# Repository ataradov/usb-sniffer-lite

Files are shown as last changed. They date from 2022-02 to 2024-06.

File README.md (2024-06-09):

# Usb Sniffer Lite for RP2040

This is a simple USB sniffer based on a Raspberry Pi RP2040. It supports Low Speed and
Full Speed modes.

The firmware presents itself as a virtual COM-port (VCP), so no additional software
is necessary and it is compatible with all operating systems.

Here are a couple of example capture logs for the [enumeration](doc/usb_fs_enumeration.txt)
and a regular [data transfer](doc/usb_fs_data.txt).

The compiled binary is available [here](bin/UsbSnifferLite.uf2). Boot RP2040 into
the BootROM mode and copy the UF2 file to the drive.

This sniffer has no packet decoding capabilities, but there is an excellent online
[USB Descriptor and Request Parser](https://eleccelerator.com/usbdescreqparser/)
that is very helpful with decoding of the standard descriptors and requests.

The compiled binary needs to have CRC value updated to be recognized by the RP2040.
This can be done using [bin2uf2](https://github.com/ataradov/tools/tree/master/bin2uf2) tool.

## Hardware Connections

USB D+ and D- signals can be directly connected to the MCU pins. The default
pin assignments are shown in the following table:

| RP2040 Pin | Function | USB Cable Color |
|:---:|:---:|:-----:|
| GND | Ground | Black |
| GPIO 10 | D+ | Green |
| GPIO 11 | D- | White |
| GPIO 12 | Start (internal) | N/A |
| GPIO 18 | Trigger | N/A |
| GPIO 25 | Status LED | N/A |
| GPIO 26 | Error LED | N/A |

The easiest way to connect the signals to the Raspberry Pi Pico board is to splice
the USB cable. It does not have to be pretty. Below is a picture of a cable that
took less than 10 minutes to make. Feel free to make it prettier.

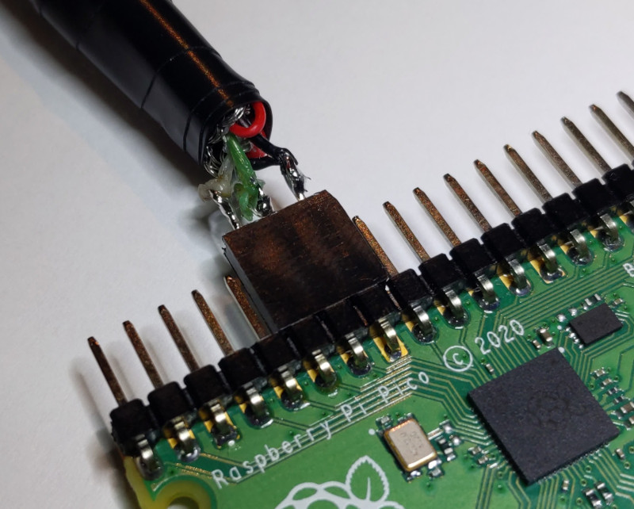
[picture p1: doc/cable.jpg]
USB Cable


[Here](doc/Hardware.md) are some pictures of a cleaner version based on
the [custom breakout board](https://github.com/ataradov/breakout-boards/tree/master/rp2040).

Trigger input is internally pulled up and the active level is low. When trigger is
enabled in the settings, the capture would pause until the trigger pin is pulled low.
Given the limited size of the capture buffer, trigger mechanism provides a way for
the debugged target to mark the part of interest.

## Dedicated Hardware

There is now a dedicated board. It integrates FE8.1 USB HUB, so you only need one
connection to the host PC. This simplifies setup a lot and eliminates wiring mess
that usually happens when working with USB sniffers.

Normally it is not advised to use the same host port for the sniffer and the target device,
but since in this case only USB Low Speed and Full Speed modes are supported, there
is plenty of bandwidth for both devices.

Schematics and Gerber files are available in the [hardware](hardware/) directory.

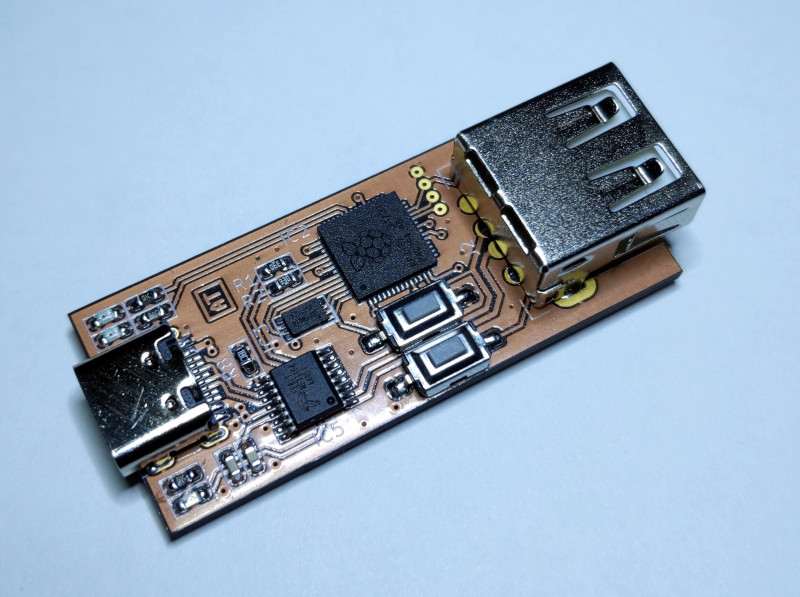
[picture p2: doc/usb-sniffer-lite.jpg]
USB Sniffer Lite PCB


## Settings

The following settings are supported:

* Capture speed (e) -- Low / Full
* Capture trigger (g) -- Enabled / Disabled
* Capture limit (l) -- 100/200/500/1000/2000/5000/10000 packets / Unlimited
* Time display format (t) -- Relative to the first packet / previous packet / SOF / bus reset
* Data display format (a) -- Full / Limit to 16 bytes / Limit to 64 bytes / Do not display data
* Fold empty frames (f) -- Enabled / Disabled

A frame is delimited by the SOF packet in the Full Speed mode or by a keep-alive signal in
the Low Speed mode.

An empty frame is a frame that contains no packets other than IN/NAK and contains no packets
with errors detected. Folding of the empty frames shortens the displayed information by
combining consecutive empty frames into one entry, since they don't carry useful information,
but happen very often in a typical USB transaction.

## Commands

The following commands are supported:

* Print the help message (h)
* Display current buffer (b)
* Start capture (s)
* Stop capture (p)

Once capture is started and the trigger condition is met, the sniffer captures the specified
number of packets. After the capture is done, the buffer is displayed using current settings.

The display settings may be adjusted without a new capture. Once the buffer is captured,
it is stored in the memory and can be displayed again using a `b` command.

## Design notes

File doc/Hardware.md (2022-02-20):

# Custom hardware version

This is the hardware based on the [custom breakout board](https://github.com/ataradov/breakout-boards/tree/master/rp2040):

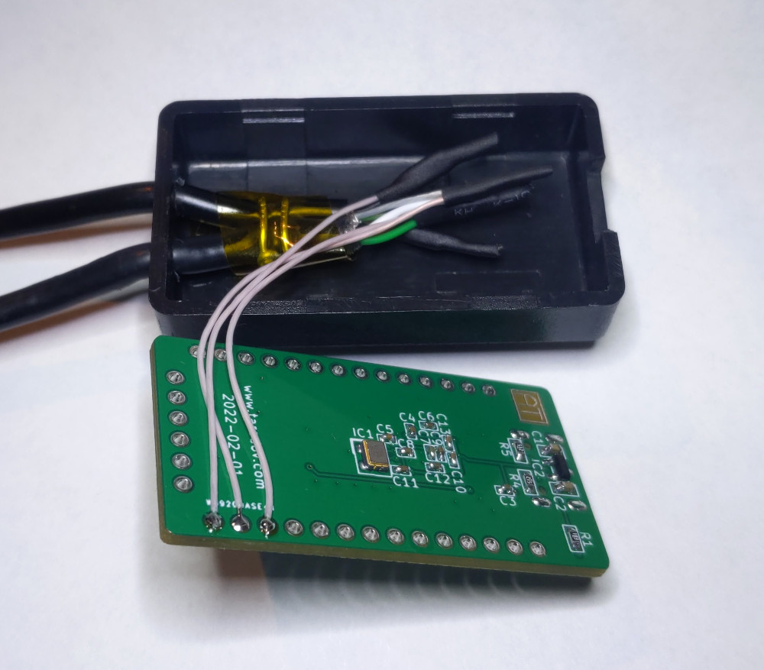
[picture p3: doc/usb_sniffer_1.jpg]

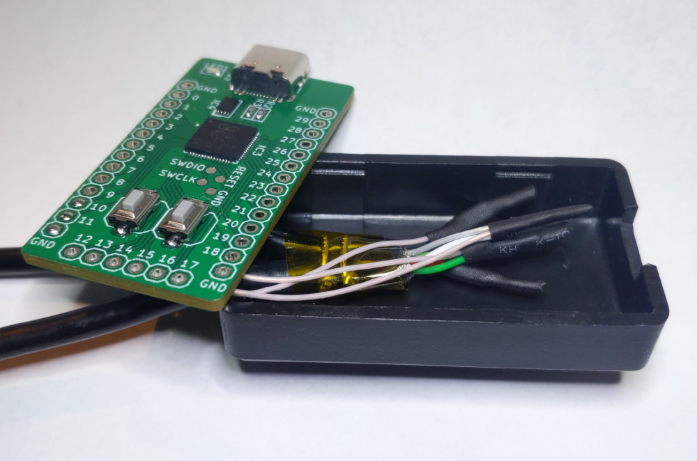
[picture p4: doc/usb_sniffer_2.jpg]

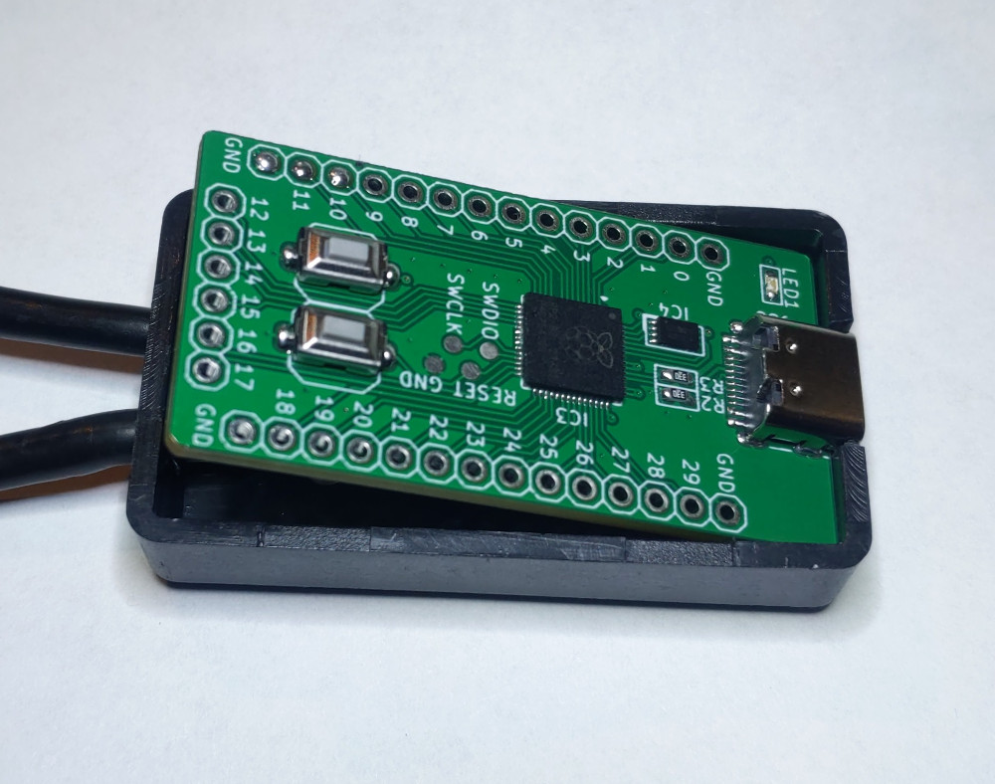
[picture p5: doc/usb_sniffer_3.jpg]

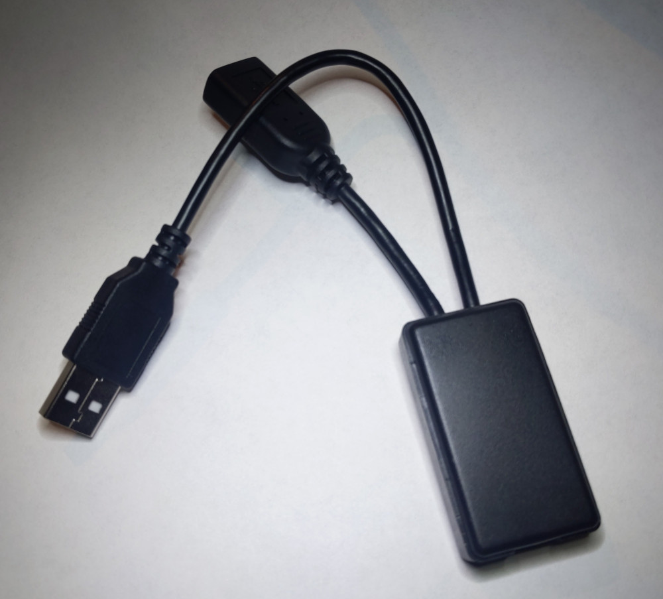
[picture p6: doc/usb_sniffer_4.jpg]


This uses a standard project box you can find on eBay or Aliexpress.
The suppliers change a lot, but usually you can find it by its dimensions: 1.97 x 1.1 x 0.59 inch / 50 x 28 x 15 mm.

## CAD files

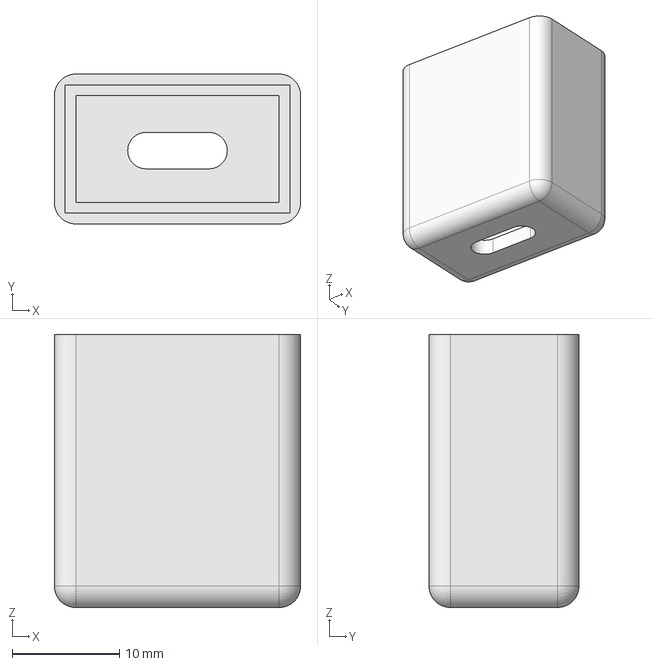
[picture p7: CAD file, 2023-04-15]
hardware/case/Case-Device.FCStd
23.0 x 14.0 x 25.5 mm

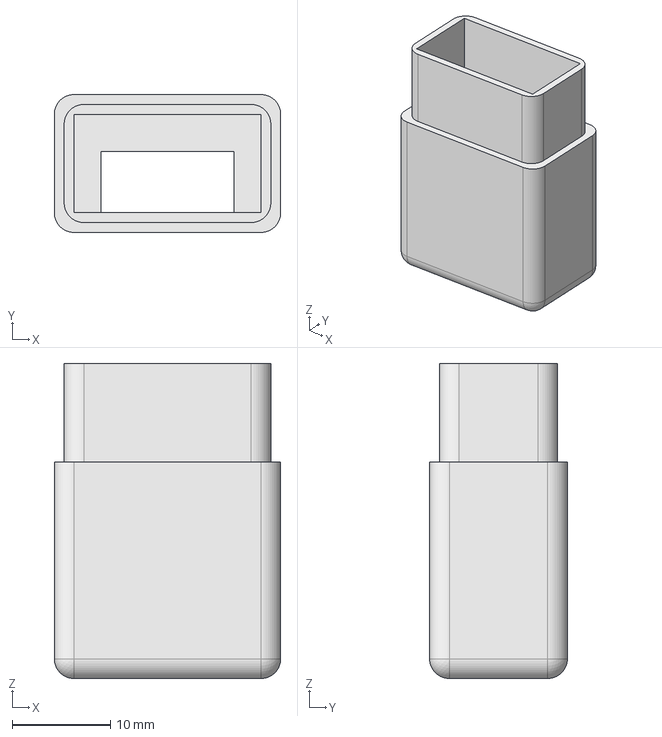
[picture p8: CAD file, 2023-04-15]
hardware/case/Case-Target.FCStd
23.0 x 14.0 x 32.0 mm

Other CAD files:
hardware/case/Case-Device.stl
hardware/case/Case-Target.stl

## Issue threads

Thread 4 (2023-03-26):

When I connect both the D+ and D- wires to the board, the connection between the testing Cool Disk with the computer is lost!

Pe3a-XaH, 2023-03-26:
Hello
Thanks for your interesting design.

I made the circuit and I saw its menu with the Putty terminal program and the LED was blinking and I used a cool disk for testing, but there was a problem.

When I disconnect one of the wires connected to GPIO 10 or GPIO 11 from the pico board, Cool Disk works and is recognized by the computer.

But when I connect both the D+ (Green) and D- (White) wires to the board, the connection between the Cool Disk and the computer is disconnected.

Please advise.

Thanks

ataradov, 2023-03-26:
What is Cool Disk?

Pe3a-XaH, 2023-03-26:
Hi,

I meant USB Flash Drives Storage.

In my country it is more famous as Cool Disk.

ataradov, 2023-03-26:
This sniffer will not be useful with flash drives. They still should function, but that depends on the quality of the connections. But sniffing will not work, since USB drives enumerate as High-Speed devices and this sniffer can only work with Full-Speed devices.

Try with something simpler, like a keyboard or a mouse.

Pe3a-XaH, 2023-03-26:
I tested with a non-smartphone and it seems to work.

I am using putty terminal with speed 576000 to communicate with pico.

But my question is how to save buffer data inside a file?
Because it is not completely possible using copy and paste.

I also get the following error at first, but after pressing the S key a couple of times to capture, it seems to get only small parts of the exchanged data correctly.

Capture started
Capture stopped
Synchronization error. Check your speed setting.

Capture buffer is empty

[When press (s) key many times ...]

1583027 : NAK
1583033 : IN: 0x02/2
1583036 : NAK
          :
          :
1583116 : NAK
1583122 : IN: 0x02/2
1583125 : NAK
1583133 : IN: 0x02/2
1583135 : DATA0 (7): 43 4d 47 52 3d 33 0d
1583143 : ACK
1583400 : IN: 0x02/2
1583403 : NAK
1583410 : IN: 0x02/2
1583413 : NAK
1583420 : IN: 0x02/2
          :
          :
1583946 : IN: 0x02/2
1583948 : NAK
   ... : Folded 1 frame

Capture buffer:
     0 : RESERVED
1869129088 : RESERVED
4154500480 : RESERVED
     0 : SPLIT: HubAddr=0x77, SC=1, Port=05, S=0, E=0, ET=2
   ... : Folded 1 frame
103123066 : SOF #551
103123078 : IN: 0x00/0
103123088 : IN: 0x00/0
103123098 : IN: 0x00/0
          :
          :
103123714 : IN: 0x00/0
103123724 : IN: 0x00/0
103123733 : IN: 0x00/0
103123829 : MDATA (280): 41 2a f8 07 f8 07 00 00 fc 03 01 00 fe 01 00 ff ...
    17 : DATA1 (4294967294):
    33 : DATA1 (43400): 25 06 20 15 27 2a 02 00 00 00 11 00 00 00 e9 8b ...
103141441 : IN: 0x00/0
103141450 : IN: 0x00/0
103141461 : IN: 0x00/0
          :
          :
103141568 : IN: 0x00/0
103141578 : IN: 0x00/0
     0 : RESERVED

[Or some time ... ]

  1021 : MDATA (280): 41 2a f8 07 f8 07 00 00 fc 03 01 00 fe 01 00 ff ff 7f 7f  ...

ataradov, 2023-03-26:
Get a better terminal that lets you save things into a file. The baudrate setting does not matter, since it is a purely virtual port.

The synchronization errors are common if device is already working and you start the capture. This sniffer assumes that the line is idle and if you start the capture in the middle of the packet, then it will not be able to synchronize properly. There may be a way to improve it, but I don't have time at the moment and in the end there is only so much PIO can do.

The optimal use for this is to start the capture, then plug int the device. This way you are guaranteed to start in the idle bus state.

Pe3a-XaH, 2023-03-26:
Thanks a lot

ataradov, 2023-04-12:
I've just pushed an update that should address a lot of synchronization issues. I expect it to be much more robust now.

Pe3a-XaH, 2023-04-24:
Hi,
Thank you for update.

I used the sniffer by Tana (https://github.com/tana/pico_usb_sniffer) for my job, because it makes Wireshark (.pcap) output.

Both of sniffers can not sniff high speed devices.

I used it series with a USB Isolator to reduce full speed devices to high speed mode, but it did  not work for me and makes many error packets.

Closed 2023-04-12.

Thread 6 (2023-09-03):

Synchronization issue

diggit, 2023-09-03:
Hi,
I have to say, this is really handy tool for USB FS debugging!
It already helped me to analyze some issues and improve bandwidth of device I am working on.
Now, I am trying to capture high load conditions. Unfortunately, I get:
```
Capture started
Capture stopped
Synchronization error. Check your speed setting.
```
I read though #4 and understood, that synchronization is problematic under load.
In my case, I have to open connection and then provide some data to load the bus. When I start capture and then open connection, packet buffer fills up before I manage to push some data.

Using trigger does not help, because it synchronizes on trigger.

Would it be possible to synchronize on start (s) and stay synced until capture is triggered?
Trigger input would serve only as a trigger for capture (storing into memory)

ataradov, 2023-09-03:
Does this happen every capture, or do you get some that work?

Do you use the most recent firmware? There was update in the most version where I wait for SE0 after the capture start. This would find the end of the packet if the capture was started in the middle.

Generally there is no way to analyze the data as it gets captured, there is not enough time for that. The only way to do this is to capture the buffer, then process it. This assumes the capture started at the beginning of the packet.

How do you use the trigger? The best way is to connect it to the device under test and in the firmware detect the condition when the traffic is about to start and set the trigger there. This way you will be starting before there is a lot of traffic. Manual triggering is essentially equivalent to the manual start without a trigger.

diggit, 2023-09-09:
I was not able to get a single sync with bus heavily loaded with Bulk IN data packets (CDC ACM, 6~18 bytes in size).
Used compiled binary linked in readme: https://github.com/ataradov/usb-sniffer-lite/blob/main/bin/UsbSnifferLite.uf2
Trigger was just a simple button. There is no simple way of triggering just before bus gets loaded.

ataradov, 2023-09-09:
Was it the most recent version of the file? It was updated multiple times and only the latest version contains sync improvements.

This behavior with the latest version is unexpected. I would debug it a bit. Capture D+/D- and GPIO18 (trigger) and GPIO12 (start). Trigger the scope on the GPIO12. You should see your trigger condition some time before the start. If trigger falls in the middle of the packet, then the start should follow right after the packet.

Otherwise the next option is to build the full version of the sniffer. PR2040 is powerful, but there are still  limits and it can't constantly monitor the bus.

FauthD, 2023-12-18:
Hi Diggit,
did you use two completely separate  busses? Even better use two PCs. One for the USB under test and the other to control the sniffer.

I developed USB devices since 1996. It often makes a difference to use two PCs, even with professional Analyzers.

Dieter :-)

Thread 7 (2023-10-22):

Pokken Tournament DX Controller Spewing Errors

zoggins, 2023-10-22:
So I am trying to sniff the communication between a Nintendo Switch and a Pokken Tournament DX controller and am just seeing it spew errors.  The controller is working fine on the switch and I have sniffed other controllers hooked up to the switch with no problems, but I am stumped as to why this controller is having issues.  I have attached a pretty typical capture of the controller.  Any advice would be appreciated.
[teraterm.log](https://github.com/ataradov/usb-sniffer-lite/files/13062180/teraterm.log)

ataradov, 2023-10-22:
This looks like either signal integrity issue or timing issue. I would guess timing, since short frames are captured fine and there are a lot of NBIT errors.

In cases like this it would be useful to look at the signal with an oscilloscope on both D+ and D-. Look at the overall shape of the waveforms and bit timing.

zoggins, 2023-10-22:
I can hook an oscilloscope up and see what I can see.  Thanks.

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

stappersg, 2024-08-04:
> I can hook an oscilloscope up and see what I can see.

What did you see?

Any other progress to report?  Like: _"With short cables it works fine, I'm suppecting voltage drop is causing the odd behaviour"_.

(How I got here:  https://hackaday.com/2024/08/03/need-a-usb-sniffer-use-your-pico/ )

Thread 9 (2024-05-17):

UART problem

noobestguy, 2024-05-17:
I'm not quite sure how to use UART0 in your "baremetal development environment." I don't want to make a mess, haha. Could you send me a small proof of concept to print some debug information at 115200 on the USB sniffer?

this dont works

```
static void uart_init(uint32_t baud)
{
  RESETS_CLR->RESET = RESETS_RESET_uart0_Msk;
  while (0 == RESETS->RESET_DONE_b.uart0);

  baud = (F_PER * 4) / baud;

  UART0->UARTIBRD = baud / 64;
  UART0->UARTFBRD = baud % 64;

  UART0->UARTLCR_H = (3/*8 bits*/ << UART0_UARTLCR_H_WLEN_Pos) | UART0_UARTLCR_H_FEN_Msk;
  UART0->UARTCR = UART0_UARTCR_UARTEN_Msk | UART0_UARTCR_RXE_Msk | UART0_UARTCR_TXE_Msk;

  HAL_GPIO_UART_TX_init();
  HAL_GPIO_UART_RX_init();
}
```

ataradov, 2024-05-17:
How exactly it does not work? How it was tested? This code is directly from the starter project that works.

Build the original starter project and check that it works on your hardware.

noobestguy, 2024-05-17:
I've done exactly that, and it doesn't work! I'm receiving garbage. :(

```
static void uart_init(uint32_t baud)
{
  RESETS_CLR->RESET = RESETS_RESET_uart0_Msk;
  while (0 == RESETS->RESET_DONE_b.uart0);

  baud = (F_PER * 4) / baud;

  UART0->UARTIBRD = baud / 64;
  UART0->UARTFBRD = baud % 64;

  UART0->UARTLCR_H = (3/*8 bits*/ << UART0_UARTLCR_H_WLEN_Pos) | UART0_UARTLCR_H_FEN_Msk;
  UART0->UARTCR = UART0_UARTCR_UARTEN_Msk | UART0_UARTCR_RXE_Msk | UART0_UARTCR_TXE_Msk;

  HAL_GPIO_UART_TX_init();
  HAL_GPIO_UART_RX_init();
}

//-----------------------------------------------------------------------------
int main(void)
{
  sys_init();
  timer_init();
  ...
  uart_init(115200);
  uart_puts("\r\nHello, world!\r\n");
```

noobestguy, 2024-05-17:
PI PICO + debug probe (for PI PICO), recv data:

00 43 21 fffd 16 fffd fffd fffd 09 fffd 271 fffd fffd 35
29 fffd

noobestguy, 2024-05-17:
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

noobestguy, 2024-05-17:
@ataradov Does this code work for you?

ataradov, 2024-05-17:
I can see junk being received by the Pico debug probe. It works fine with other adapters.

It also works fine after the initial Hello World string. If you type characters, it will echo them back correctly.

I assume this is some bug in the pico probe. It may not like initial level transitions when device is reset or something like this.

Try with a different USB to UART adapter.

noobestguy, 2024-05-17:
oh, right!

sleeping a little.. and it works:
```
  uart_init(115200);
  for (uint32_t a = 0; a < 1000000; a++) {b++;};

  uart_puts("\r\nHello, world!\r\n");
  uart_puts("\r\nHello, world!\r\n");
```

noobestguy, 2024-05-17:
Thank you very much for the help. How can I implement a sleep function for X milliseconds in your baremetal environment?

ataradov, 2024-05-17:
The same way as on any other MCU:
```
static void delay_ms(int ms)
{
  uint32_t cycles = ms * F_CPU / 3 / 1000;

  asm volatile (
    "1: sub %[cycles], %[cycles], #1 \n"
    "   bne 1b \n"
    : [cycles] "+r"(cycles)
  );
}
```
Normally you would want this to be located in the RAM through the section attribute, but in this case it already runs from the RAM.

noobestguy, 2024-05-17:
Great! Is there a way to generate the ELF file to debug it? I think there might be something wrong with the checksums or something. The U2F with your tool works great, but I'd like to use OpenOCD for debugging.

ataradov, 2024-05-17:
You can get the CRC value generated by the tool and place it in the linker script instead of a dummy value LONG(0xcccccccc).

The value would be different for different compilers, but you can get it by running
```
bin2uf2 -s -i UsbSnifferLite.bin -o UsbSnifferLite.bin
```

It will show you the correct CRC. In my case it is 0x76b0d78e. So you would replace LONG(0xcccccccc) with LONG(0x76b0d78e).

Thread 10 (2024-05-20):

Does not function yet

WillemOuwerkerk, 2024-05-20:
Hi Ataradov,

I installed the UF2 and made me a primitive cable.
Can get the menu in a terminal screen, but i can't get it to capture any data.
Both USB connectors are connected to the same bus.

And i do not understand the function of the start key, can you explain this to me?

Kind regards,
Willem Ouwerkerk

ataradov, 2024-05-20:
What do you mean by the "same bus"? Can you describe your connections in more detail? What is your device under test?

WillemOuwerkerk, 2024-05-20:
They are connected to the same USB hub
What is the difference between the START key and the trigger key?

ataradov, 2024-05-20:
What exact device you are trying to capture? What IC is it based on? Are you sure it is FS/LS device?

Trigger is not a key, it is a signal. If enabled, then after you start the capture, the sniffer will wait for the trigger signal. It is useful if you are debugging your own firmware and can toggle a GPIO at the point of interest. If you are capturing existing devices, then trigger is rarely useful. Disable it.

WillemOuwerkerk, 2024-05-20:
Ok now i understand it's function, nice.
The dongle is a PL2302just to try it out
I want to use it to write a custom RP2040 usb driver

ataradov, 2024-05-20:
PL2302 is a Full-Speed device, so you should be able to capture it. If you don't see any frames when you start the capture, then you will have to provide more details of your setup.

What custom USB driver? I'm confused.

WillemOuwerkerk, 2024-05-20:
Oh i just want to understand the built-in USB of the RP2040
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

ataradov, 2024-05-20:
This photo is not useful at all. There is nothing I can tell from it.

If you just want to understand USB part, then this project may be more useful https://github.com/ataradov/free-dap/tree/master/platform/rp2040 It is a CMSIS-DAP programmer + VCP without complexities of the sniffer part.

WillemOuwerkerk, 2024-05-20:
What do you need to know from me tot help me?
Is the start key toggle or need i keep it pressed?

made the simple connector as you adviced to GPIO10 & 11
A switch to GPIO12 and the status led blinks

I plugged all devices including the sniffer in the same usb-hub.

WillemOuwerkerk, 2024-05-20:
Hi Alex,

Now i think that i start to understand how it must be used. Is it like this?

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

WillemOuwerkerk, 2024-05-20:
Thanks, i am going to make the correct cable
Also thanks for the pointer to your example code

WillemOuwerkerk, 2024-05-27:
Thanks Alex, it's working now

ataradov, 2024-05-27:
Closing the issue then.

Closed 2024-05-27.

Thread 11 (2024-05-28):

development environment

1250364116, 2024-05-28:
hi, i'm trying to use your code. my question is what sort of SDK or toolchain can compile your code?
i tried to compile your code by official SDK that raspbery has published for pico boards, but it seems that sdk has been designed to work
with pico/stdlib.h  not your rp2040.h library.

ataradov, 2024-05-28:
There is no development environment. There is just a Makefile in the build directory. You run make there and you get binary files.

You need to have ARM GCC and make in your Path.

1250364116, 2024-05-28:
thanks.sorry i ask you simple questions because I am new to this Raspberry microcontroller, so as I understood you suggest
to build binary file without using any ide.

ataradov, 2024-05-28:
The project includes all that is necessary for the build. There are no external dependencies. You can add all the files to some IDE if you want, but you don't have to do it. And I can't help you with the IDEs, since I don't use them.

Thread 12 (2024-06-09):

BIN2UF2 PROBLEM

1250364116, 2024-06-09:
Hi. i tried to compile your code in Ubuntu, I have ARM GCC and Make in my Linux PATH. but when i try to run Makefile it gives an error
that bin2uf2 does not exist. I tried to find bin2uf2 for ubuntu but didn't find something useful. Where did you find bin2uf2?

ataradov, 2024-06-09:
It is linked in the main readme https://github.com/ataradov/tools/tree/master/bin2uf2 I've also edited it just now to make it even more apparent.

1250364116, 2024-06-10:
thanks a lot

stappersg, 2024-08-04:
> thanks a lot

Acknowledge on the _"thanks a lot"_. Now this issue waits for someone to close it. (So this issue would**n't** drain further human energy.)

Closed 2024-08-04.

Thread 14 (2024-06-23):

Error issue

1250364116, 2024-06-23:
hi, i am testing your code. it gives for each keystroke an error. can you help me?

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

ataradov, 2024-06-23:
This looks like legitimately broken frames. The decoded data must be correct, since overall flow is not broken.

My only guess here is that device clock frequency is way off and the error accumulates on the long packets, but the short ones are received correctly.

I would try with a different target device to see if you get a different result.

Closed 2024-08-28.

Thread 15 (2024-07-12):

other rp2040 libraries

1250364116, 2024-07-12:
hello. i think your libraries for rp2040 is far more better for developing new programs by rp2040 than its SDK libraries distributed by its company. i want to know, have you developed libraries for other rp2040 peripherals like SPI or UART? if yes, can I have those?

ataradov, 2024-07-12:
Simple UART example is available here https://github.com/ataradov/mcu-starter-projects/blob/master/rp2040/main.c
A more complete example is here https://github.com/ataradov/free-dap/blob/master/platform/rp2040/uart.c

I don't have examples for SPI.

Closed 2024-08-28.

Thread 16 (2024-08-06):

PIO frequency

1250364116, 2024-08-06:
Hello,

I would like to know the PIO clock frequency. From what I understand, in low-speed mode the PIO clock divider is set to 8, and in full-speed mode, the divider is set to 1. Given that the system clock frequency is 120 MHz, this means that the PIO clock would be 120 MHz in full-speed mode and 15 MHz in low-speed mode.Similarly, for the USB clock, in low-speed mode, the frequency is 1.5 MHz, and in full-speed mode, it is 12 MHz.
 Is this correct? If so, why is the PIO frequency ten times higher than the USB clock frequency?

ataradov, 2024-08-06:
Your understanding is correct. It needs to be 10 times faster because PIO does not know where the bit centers are. It works with the raw captured pin samples, so it needs extra to synchronize and track the bit centers.

Fixed hardware implementations do the same exact thing. You will typically see that FS devices required 48 MHz clock. This is 4 times faster than the bit rate.

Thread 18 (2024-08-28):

continuous data capture

1250364116, 2024-08-28:
Hi, your program always needs a start button to be pushed to capture the data, and it will stop after a few moments.
how it will be if I try to make the logger to capture the data continuously without any start command?
Is there any consideration I need to make about changing the program in this way?

ataradov, 2024-08-28:
It is not possible. The performance of RP2040 only allows for the buffer capture with the decoding after that. And the capture time is limited by the buffer size

You will need need to build the full version of the sniffer to have a continuous capture.

1250364116, 2024-08-28:
What if one core only captures and saves the data in a two dimensional
array, when the logger reaches the end of the first array buffer size, the
capture would restart and saves the data in the second array while in the
other core we process the first array datas and after completion of
processing wait for other array to be filled with new datas?

در تاریخ چهارشنبه ۲۸ اوت ۲۰۲۴،‏ ۱۷:۰۷ Alex Taradov ***@***.***>
نوشت:

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

ataradov, 2024-08-28:
You can't print over USB fast enough to output all the data. The speed of the device USB and capture USB is the same. And printing the data, expands the actual size a lot, since it is now represented in a human-readable format.

You can probably figure out something, especially if you don't print all the data. But I have no interest in implementing that. If you really need the continuous transfer, then use the full sniffer. It is more expensive, of course, but it is way more functional.

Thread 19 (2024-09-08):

contents of the buffer

1250364116, 2024-09-08:
hello. As I see, the pio0 for each 32-bit sampled data fills the buffer by two values: the size of the sampled data and the sampled 32-bit data itself. then you add the end time of sampling that data as the third element. thus for each 32 data sampling, the buffer is filled by 3 elements in a row. but sometimes pio0 pushes out another element as a fourth value which is 0xFFFFFFFF.
so, what is this value and what does it mean? is it a flag for the end of the frame?

ataradov, 2024-09-08:
The size of the data from the PIO is indicated as 0xffffffff-actual size (it counts down from 0xffffffff) and the data is limited to 31 bits. So, highest bit can be used to distinguish size (end of packet) from the data bits.

The only time PIO0 can push 0xffffffff is when the actual size is 0, and that only happens in the case of a line reset (D+=low, D-=low), which appears as a valid start of packet marker, but then does not have synchronization field.

But 0xffffffff is never pushed as an additional data, it is always pushed as a length part.

1250364116, 2024-09-08:
So for each data sample, g.buffer is filled only with 3 elements: size,
time, data itself.

در تاریخ یکشنبه ۸ سپتامبر ۲۰۲۴،‏ ۱۸:۵۳ Alex Taradov <
***@***.***> نوشت:

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

ataradov, 2024-09-08:
Correct. You get data + size from the PIO itself and the time is added in the loop after the last element is read from the PIO.

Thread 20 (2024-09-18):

synchronization error

1250364116, 2024-09-18:
hi alex. when i work with keyboard the device prints accidently synchronization error message. in other words device captures the strokes in some cycles and does not capture anything in other times because of synchronization error while I have configured the device speed correctly. what this synchronization error exactly means? because I saw when the size is more than 0xffff this message is printed out. what does this criteria mean?

ataradov, 2024-09-18:
Synchronization error means that you likely started the capture in the middle of the packet and when this happens, there is no way it can recover, since it needs to track start of packet and end of packet markers to know when the packets start and end.

If this happens in the middle of the capture, then there is likely some noise on the line that gets interpreted as SOP, but EOP is not received for a long time.

This is an unfortunate side effect of the low performance device, there is no way to reliably detect the idle state. I made some improvements towards that in the recent updates and it made things better, but still not 100%.

This is why it works better when the sniffed device is reset before the capture starts, so there is no chance of capture starting in the middle of the packet.

ataradov, 2024-09-18:
Note that there are a few vendors selling the hardware for the full snuffer on AliExpress now. I don't endorse any if them, but they are there if you want to try. And if you are doing serious work, then having the full version is so much better.

1250364116, 2024-09-18:
Thanks, i saw some of those devices but i want something a little bit
different.
Excuse me to take your time,
as you said if the pio usb sampler finds the start of the bit then it will
sample the data synchronized till something stopes it, so if nothing stops
the pio, i do not think the pio would miss the start of the bit.
Second, you mean the keyboard has low Performance which causes noises? Or
this is microcontroller?

در تاریخ چهارشنبه ۱۸ سپتامبر ۲۰۲۴،‏ ۸:۳۳ Alex Taradov <
***@***.***> نوشت:

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

ataradov, 2024-09-18:
It is not start of the bit, but start of the packet. SOP is denoted by a switch from idle to the K state. The sniffer does not have enough resources to really observe the idle state, I just assume that the line is idle and wait for the K state. But the K state is also used in signalling the bit states. So, if start the capture in the middle of the packet, it can't  correctly receive the data.

Ideally capture need to observe both D+ and D- to make complete decisions about the line state, but PIO does not have enough resources to do so. I observe one line and derive the state of the other.

If the sync issue happens in the middle of the capture, then it may be the noise created by the wiring setup. Long exposed unshielded cables would pickup some noise. If the sync issue happen at the begging of the capture, it is just an unfortunate timing.

There is a chance you can do a bit better in finding the idle state before starting the capture, but I don't have any interest in doing so. When you can have a real sniffer for $30, wasting time on this very limited one does not seem to be worth it.

1250364116, 2024-09-24:
thank you, i have read what you have explained about pio asm code, and the possibility of starting the capture when the line is in the middle of a packet. thus some problems created in my mind:
first I understand the pio asm execution code sequence as follow:

1-the first moment after a reset or powering on, the PIO0 SM, executes line 31 of the code:

    /* 31 */ OP_WAIT | WAIT_POL_1 | WAIT_SRC_PIN | WAIT_INDEX(2),

in which the PIO0 waits for PIO1 to trigger the start pin.PIO1, first checks
the EOP by executing the code bellow for multiple times:

    /* 4 */  OP_MOV | MOV_DST_OSR | MOV_SRC_PINS | MOV_OP_BIT_REV,
    /* 5 */  OP_OUT | OUT_DST_Y | OUT_CNT(2),
    /* 6 */  OP_JMP | JMP_COND_Y_NZ_PD | JMP_ADDR(4/*wait_se0*/),

and then after ensuring the EOP, in USB line, it triggers start pin as follow:

    /* 16 */ OP_SET | SET_DST_PINS | SET_DATA(1), // Set the START output
    /* 17 */ OP_JMP | JMP_ADDR(17/*self*/), // Infinite loop

So, pio1 is sparing pio0 ,the first time after powering on, to recognize the first J state as idle(in low-speed mode) and we cannot
expect the capture unit to get into the packet's middle, while pio1 is performing like this. this is my opinion about start of capture after powering on or reset.

2.after the first idle state and SOP, the code always samples the packet bits exactly in the 5th cycle after the bit starts(as you
mentioned before the pio clock is 10 times of USB clock so it is exactly the middle of the bit), till the time EOP situation happens, so when the sampler sees EOP it pushes out both data and (0xfffffff-size), and then goes to these lines:

    // poll_loop:
    /* 25 */ OP_MOV | MOV_DST_OSR | MOV_SRC_PINS | MOV_OP_BIT_REV, // Sample D+ and D-
    /* 26 */ OP_OUT | OUT_DST_Y | OUT_CNT(2),
    /* 27 */ OP_JMP | JMP_COND_Y_NZ_PD | JMP_ADDR(0/*idle*/), // If either is not zero, back to idle
    /* 28 */ OP_JMP | JMP_COND_X_NZ_PD | JMP_ADDR(25/*poll_loop*/),
    /* 29 */ OP_MOV | MOV_DST_ISR | MOV_SRC_NULL | MOV_OP_INVERT,
    /* 30 */ OP_PUSH,
    // Wrap to 0 from here

in the code above, the sampler is checking if the USB line remains in the EOP yet(by sampling both lines), or something else has happened. this will be repeated 31 times, if the line does not exit the EOP state after 31 cycles sampler will push a 0xffffffff number(perhaps as a USB reset flag) and then everything wraps to the first line where sampler is looking for an idle state.

so my conclusion is, when the PIO is looking for an idle state in the first line I think we are sure that certainly an EOP situation is exactly the last thing has happened before, because as I see the sampler can get to the first line in two ways, first after a start signal triggered by PIO1, second after EOP of the last sampled packet. and in both situations the capture cannot start from the middle of the packet if we use a proper clock for the PIO.
(so the synchronization error happens if USB frequency and pio frequency does not match)

ataradov, 2024-09-24:
Your reasoning is correct. The EOP detection PIO was added much later and it reduced synchronization errors by a lot, but not entirely. I'm not so sure about your conclusion though. I don't think it has anything to odd with the clock mismatch.

The state machine here actually implements tracking of the clock and the sample point constantly adjusting, just like regular USB controllers do, so in theory it should be able to track any reasonable frequency deviceations.

It is possible that there is some bug in that tracking or somewhere else, or some other scenario that we don't take into account. You can debug that if you want, I personally don't have any interest in it. This project was just a training to figure out how PIOs work and it achieved its goal. It is useful in a pinch, but if you really need to do any real work, use real tools.

1250364116, 2024-09-24:
Thank you for the answer.

در تاریخ سه‌شنبه ۲۴ سپتامبر ۲۰۲۴،‏ ۱۷:۱۷ Alex Taradov <
***@***.***> نوشت:

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

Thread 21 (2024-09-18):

Excuse me to take your time, 1250364116

stappersg, 2024-09-18:
Thanks, i saw some of those devices but i want something a little bit
different.
Excuse me to take your time,
as you said if the pio usb sampler finds the start of the bit then it will
sample the data synchronized till something stopes it, so if nothing stops
the pio, i do not think the pio would miss the start of the bit.
Second, you mean the keyboard has low Performance which causes noises? Or
this is microcontroller?

_Originally posted by @1250364116 in https://github.com/ataradov/usb-sniffer-lite/issues/20#issuecomment-2357562992_
   
Before opening this issue, had this project 9 issue open. 6 of them were opened by @1250364116. All six got an answer from @ataradov.  None those answers were used by  @1250364116 to improve the documentation. However  @1250364116 keeps  taking without giving  back.

This issue is for creating awareness of that unbalanced situation.

1250364116, 2024-09-24:
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

excuse me, but if you look at what I have asked, you will understand most of them are questions about how this code works, so my feedback is only to thank Mr. Ataradov for answering my questions generously.

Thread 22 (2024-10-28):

Windows 7 driver issues

kovapatrik, 2024-10-28:
So I'm trying to use this inside a Windows 7 VM, and the driver doesn't install itself on this OS. I tried to use the FTDI VCP drivers but without success. What driver should I use for this to work?

ataradov, 2024-10-28:
You need an INF file referencing usbser.sys driver. There is not a universal one. Here is one from a long time ago for a Atmel Raven USB Stick. You will need to edit this and change VID/PID and optionally strings.
[RZUsbStick.txt](https://github.com/user-attachments/files/17549869/RZUsbStick.txt) (rename to *.inf)

kovapatrik, 2024-10-29:
I just found a similar solution just after I made the issue, but thanks for the help!!

Closed 2024-10-29.

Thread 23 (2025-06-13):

Off topic dual CDC question

WillemOuwerkerk, 2025-06-13:
Hi Alex,

I have a single CDC port working nicely thanks to your example driver and your sniffer.
Many thanks for that.

I like to open a second CDC port on the RP2040, but i can not find relevant data to
change the configuration tables and the hardware setup for the RP2040.
My question is can you give me a hint on how to do that or where to look for more data.

Kind regards,
Willem Ouwerkerk.

ataradov, 2025-06-13:
What interrupt endpoint?

There is ep_comm, which will have a coy as part of the full copy  of everything from iad to ep_out. There is no need for additional endpoints.

WillemOuwerkerk, 2025-06-13:
Sorry Alex,

These are the endpoints that i use now:
Endpoint 0 for setup requests
Endpoint 1 for communication requests
Endpoint 2 as IN endpoint (send to host)
Endpoint 3 as OUT endpoint ( data from host)

ataradov, 2025-06-13:
As I said, to get the second port you need to copy the whole part of the configuration hierarchy that corresponds to the port. This includes all the descriptors from  iad to ep_out.

You will have to read and understand how CDC works if you want to make it work, so reading the spec is a good start.

Or find some example configuration descriptor that has two COM ports. But you will still need to change the source code past the descriptor part, so you will still need to understand how it works.

WillemOuwerkerk, 2025-06-13:
Yes i understand that,
That is what i am trying to do, what is the best source for documentation?
Most documents i have are quite general

WillemOuwerkerk, 2025-06-13:
Thanks Alex,

I will come back to you when i have more relevant info.

Thanks for now,
Willem.

andygpz11, 2025-06-13:
@WillemOuwerkerk I have previously got two CDC channels working on RP2040 starting from code from the pico-sdk:

`pico-sdk/lib/tinyusb/examples/device/cdc_dual_ports`

The dimension that defines the number of CDC interfaces is `CFG_TUD_CDC`.

Hope this helps.

WillemOuwerkerk, 2025-06-13:
Thanks Alex, going to try and read it all.

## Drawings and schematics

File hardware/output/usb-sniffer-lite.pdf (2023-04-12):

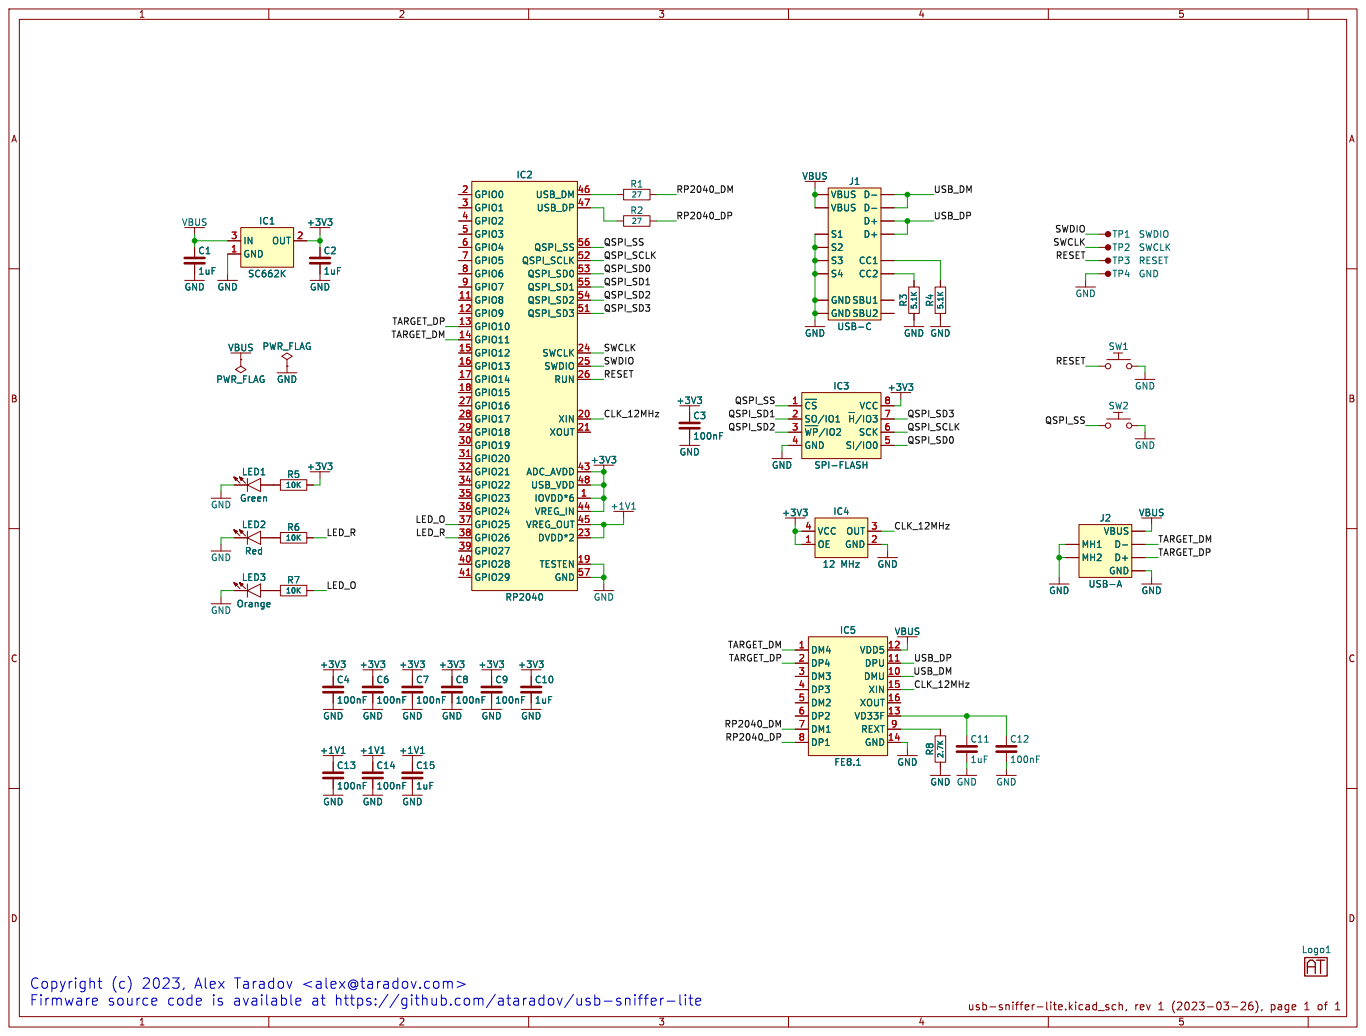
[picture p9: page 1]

QSPI_SD1 Copyright (c) 2023, Alex Taradov <alex@taradov.com>

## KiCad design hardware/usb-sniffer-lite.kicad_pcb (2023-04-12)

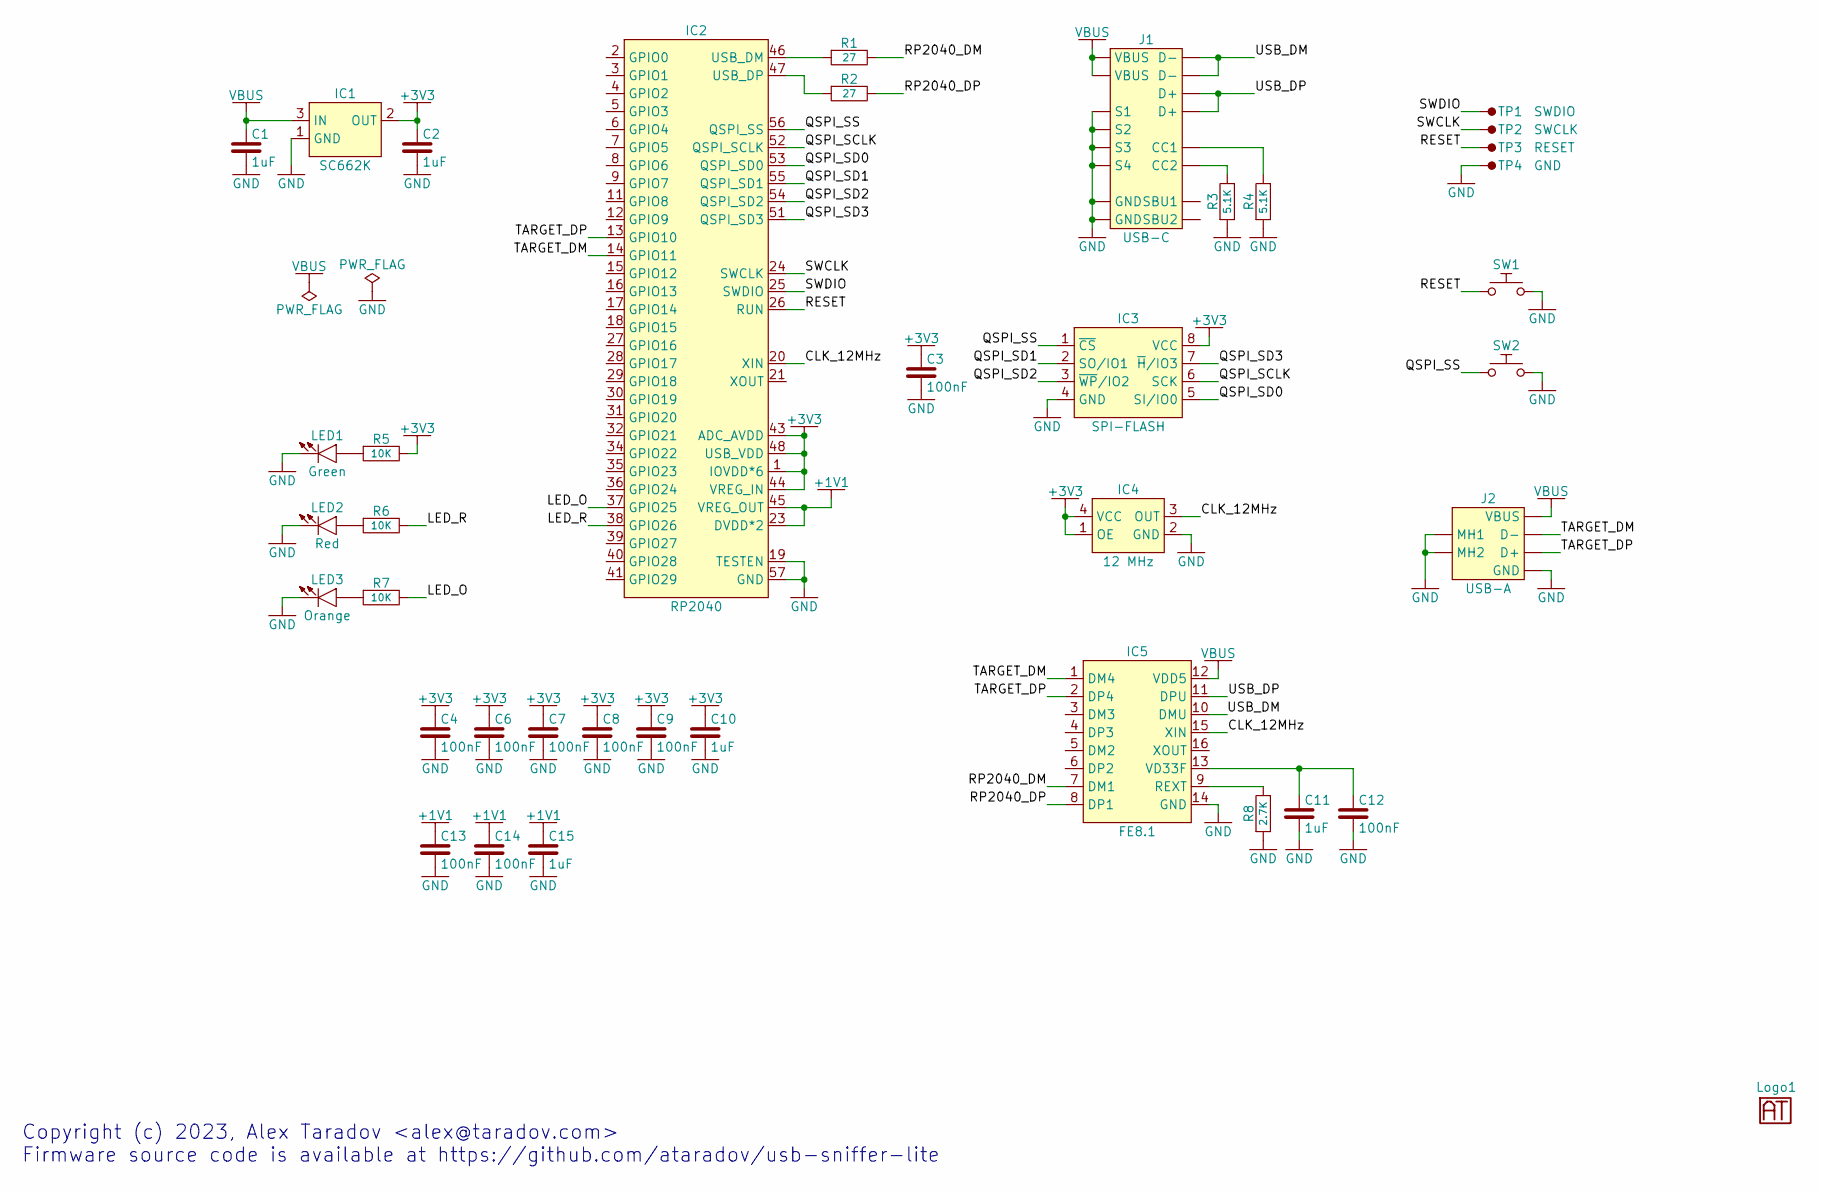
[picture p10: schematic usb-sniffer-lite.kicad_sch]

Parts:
C1, C2, C10, C11, C15: 1uF; 0603
C3, C4, C6, C7, C8, C9, C12, C13, C14: 100nF; 0603
IC1: SC662K; SOT-23
IC2: RP2040; QFN-56-0.4mm
IC3: SPI-FLASH; USON-8-3x2mm
IC4: 12 MHz; CDFN-4-3.2x2.5mm
IC5: FE8.1; SSOP-16-0.635mm
J1: USB-C
J2: USB-A; USB-A-Slots
LED1: Green; 0603
LED2: Red; 0603
LED3: Orange; 0603
Logo1: Logo; Logo-Small
R1, R2: 27; 0603
R3, R4: 5.1K; 0603
R5, R6, R7: 10K; 0603
R8: 2.7K; 0603
SW1, SW2: TactSwitch; TactSwitch-6mm-Half-SMD
TP1: SWDIO; TestPoint-1.27mm-Small
TP2: SWCLK; TestPoint-1.27mm-Small
TP3: RESET; TestPoint-1.27mm-Small
TP4: GND; TestPoint-1.27mm-Small

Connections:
+1V1: C13.2, C14.2, C15.2, IC2.23 (DVDD*2), IC2.45 (VREG_OUT), IC2.50 (DVDD*2)
+3V3: C2.2, C3.2, C4.2, C6.2, C7.2, C8.2, C9.2, C10.2, IC1.2 (OUT), IC2.1 (IOVDD*6), IC2.10 (IOVDD*6), IC2.22 (IOVDD*6), IC2.33 (IOVDD*6), IC2.42 (IOVDD*6), IC2.43 (ADC_AVDD), IC2.44 (VREG_IN), IC2.48 (USB_VDD), IC2.49 (IOVDD*6), IC3.8 (VCC), IC4.1 (OE), IC4.4 (VCC), R5.2
/CLK_12MHz: IC2.20 (XIN), IC4.3 (OUT), IC5.15 (XIN)
/LED_O: IC2.37 (GPIO25), R7.2
/LED_R: IC2.38 (GPIO26), R6.2
/QSPI_SCLK: IC2.52 (QSPI_SCLK), IC3.6 (SCK)
/QSPI_SD0: IC2.53 (QSPI_SD0), IC3.5 (SI/IO0)
/QSPI_SD1: IC2.55 (QSPI_SD1), IC3.2 (SO/IO1)
/QSPI_SD2: IC2.54 (QSPI_SD2), IC3.3 (~WP/IO2)
/QSPI_SD3: IC2.51 (QSPI_SD3), IC3.7 (~H/IO3)
/QSPI_SS: IC2.56 (QSPI_SS), IC3.1 (~CS), SW2.1
/RESET: IC2.26 (RUN), SW1.1, TP3.1
/RP2040_DM: IC5.7 (DM1), R1.2
/RP2040_DP: IC5.8 (DP1), R2.2
/SWCLK: IC2.24 (SWCLK), TP2.1
/SWDIO: IC2.25 (SWDIO), TP1.1
/TARGET_DM: IC2.14 (GPIO11), IC5.1 (DM4), J2.D-
/TARGET_DP: IC2.13 (GPIO10), IC5.2 (DP4), J2.D+
/USB_DM: IC5.10 (DMU), J1.D-1 (D-), J1.D-2 (D-)
/USB_DP: IC5.11 (DPU), J1.D+1 (D+), J1.D+2 (D+)
GND: C1.1, C2.1, C3.1, C4.1, C6.1, C7.1, C8.1, C9.1, C10.1, C11.1, C12.1, C13.1, C14.1, C15.1, IC1.1 (GND), IC2.19 (TESTEN), IC2.57 (GND), IC3.4 (GND), IC4.2 (GND), IC5.14 (GND), J1.GND1 (GND), J1.GND2 (GND), J1.S1, J1.S2, J1.S3, J1.S4, J2.GND, J2.MH1, J2.MH2, LED1.2 (K), LED2.2 (K), LED3.2 (K), R3.1, R4.1, R8.1, SW1.2, SW2.2, TP4.1
unnamed: IC2.46 (USB_DM), R1.1
unnamed: IC2.47 (USB_DP), R2.1
unnamed: IC5.9 (REXT), R8.2
unnamed: C11.2, C12.2, IC5.13 (VD33F)
unnamed: J1.CC1, R4.2
unnamed: J1.CC2, R3.2
unnamed: LED1.1 (A), R5.1
unnamed: LED2.1 (A), R6.1
unnamed: LED3.1 (A), R7.1
VBUS: C1.2, IC1.3 (IN), IC5.12 (VDD5), J1.VBUS1 (VBUS), J1.VBUS2 (VBUS), J2.VBUS

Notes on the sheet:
Copyright (c) 2023, Alex Taradov <alex@taradov.com> Firmware source code is available at https://github.com/ataradov/usb-sniffer-lite

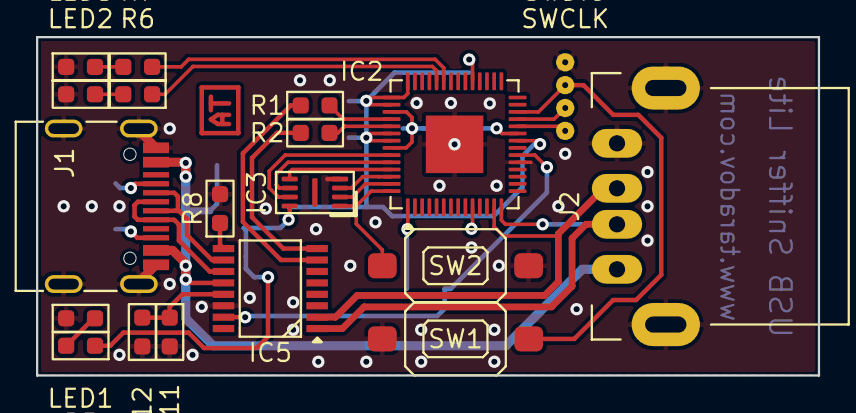
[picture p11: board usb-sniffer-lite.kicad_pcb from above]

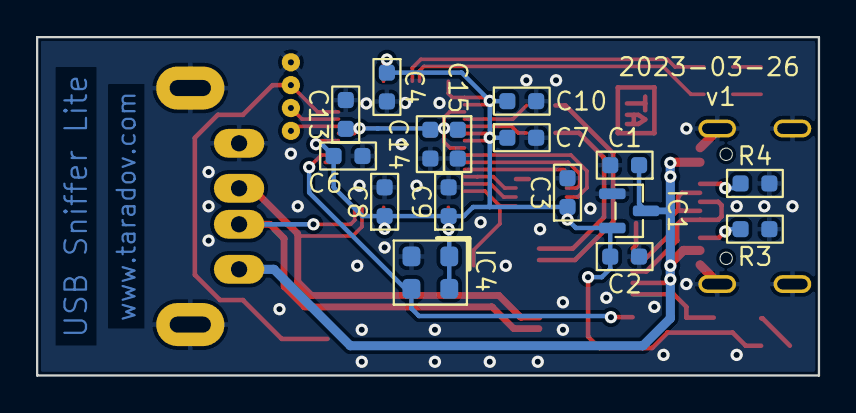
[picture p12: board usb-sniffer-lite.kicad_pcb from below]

Board: 2 copper layers, 43.4 x 18.8 mm, 39 parts (16 on the bottom side), 31 nets.

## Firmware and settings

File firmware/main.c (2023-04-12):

// SPDX-License-Identifier: BSD-3-Clause
// Copyright (c) 2022, Alex Taradov <alex@taradov.com>. All rights reserved.

/*- Includes ----------------------------------------------------------------*/
#include <stdlib.h>
#include <stdint.h>
#include <stdbool.h>
#include <string.h>
#include "rp2040.h"
#include "hal_gpio.h"
#include "capture.h"
#include "globals.h"
#include "utils.h"
#include "usb.h"

/*- Definitions -------------------------------------------------------------*/
#define F_REF      12000000
#define F_CPU      120000000
#define F_PER      120000000
#define F_RTC      (F_REF / 256)
#define F_TICK     1000000

#define USB_BUFFER_SIZE    64
#define VCP_TIMEOUT        10000 // us
#define STATUS_TIMEOUT     500000 // us

HAL_GPIO_PIN(LED_O, 0, 25, sio_25)
HAL_GPIO_PIN(LED_R, 0, 26, sio_26)

/*- Variables ---------------------------------------------------------------*/
static uint8_t app_recv_buffer[USB_BUFFER_SIZE];
static uint8_t app_send_buffer[USB_BUFFER_SIZE];
static int app_send_buffer_ptr = 0;
static bool app_send_zlp = false;
static bool app_send_pending = false;
static bool app_recv_pending = false;
static bool app_vcp_open = false;

/*- Implementations ---------------------------------------------------------*/

//-----------------------------------------------------------------------------
static void sys_init(void)
{
  // Enable XOSC
  XOSC->CTRL     = (XOSC_CTRL_FREQ_RANGE_1_15MHZ << XOSC_CTRL_FREQ_RANGE_Pos);
  XOSC->STARTUP  = 47; // ~1 ms @ 12 MHz
  XOSC_SET->CTRL = (XOSC_CTRL_ENABLE_ENABLE << XOSC_CTRL_ENABLE_Pos);
  while (0 == (XOSC->STATUS & XOSC_STATUS_STABLE_Msk));

  // Setup SYS PLL for 12 MHz * 40 / 4 / 1 = 120 MHz
  RESETS_CLR->RESET = RESETS_RESET_pll_sys_Msk;
  while (0 == RESETS->RESET_DONE_b.pll_sys);

  PLL_SYS->CS = (1 << PLL_SYS_CS_REFDIV_Pos);
  PLL_SYS->FBDIV_INT = 40;
  PLL_SYS->PRIM = (4 << PLL_SYS_PRIM_POSTDIV1_Pos) | (1 << PLL_SYS_PRIM_POSTDIV2_Pos);

  PLL_SYS_CLR->PWR = PLL_SYS_PWR_VCOPD_Msk | PLL_SYS_PWR_PD_Msk;
  while (0 == PLL_SYS->CS_b.LOCK);

  PLL_SYS_CLR->PWR = PLL_SYS_PWR_POSTDIVPD_Msk;

  // Setup USB PLL for 12 MHz * 36 / 3 / 3 = 48 MHz
  RESETS_CLR->RESET = RESETS_RESET_pll_usb_Msk;
  while (0 == RESETS->RESET_DONE_b.pll_usb);

  PLL_USB->CS = (1 << PLL_SYS_CS_REFDIV_Pos);
  PLL_USB->FBDIV_INT = 36;
  PLL_USB->PRIM = (3 << PLL_SYS_PRIM_POSTDIV1_Pos) | (3 << PLL_SYS_PRIM_POSTDIV2_Pos);

  PLL_USB_CLR->PWR = PLL_SYS_PWR_VCOPD_Msk | PLL_SYS_PWR_PD_Msk;
  while (0 == PLL_USB->CS_b.LOCK);

  PLL_USB_CLR->PWR = PLL_SYS_PWR_POSTDIVPD_Msk;

  // Switch clocks to their final socurces
  CLOCKS->CLK_REF_CTRL = (CLOCKS_CLK_REF_CTRL_SRC_xosc_clksrc << CLOCKS_CLK_REF_CTRL_SRC_Pos);

  CLOCKS->CLK_SYS_CTRL = (CLOCKS_CLK_SYS_CTRL_AUXSRC_clksrc_pll_sys << CLOCKS_CLK_SYS_CTRL_AUXSRC_Pos);
  CLOCKS_SET->CLK_SYS_CTRL = (CLOCKS_CLK_SYS_CTRL_SRC_clksrc_clk_sys_aux << CLOCKS_CLK_SYS_CTRL_SRC_Pos);

  CLOCKS->CLK_PERI_CTRL = CLOCKS_CLK_PERI_CTRL_ENABLE_Msk |
      (CLOCKS_CLK_PERI_CTRL_AUXSRC_clk_sys << CLOCKS_CLK_PERI_CTRL_AUXSRC_Pos);

  CLOCKS->CLK_USB_CTRL = CLOCKS_CLK_USB_CTRL_ENABLE_Msk |
      (CLOCKS_CLK_USB_CTRL_AUXSRC_clksrc_pll_usb << CLOCKS_CLK_USB_CTRL_AUXSRC_Pos);

  CLOCKS->CLK_ADC_CTRL = CLOCKS_CLK_ADC_CTRL_ENABLE_Msk |
      (CLOCKS_CLK_ADC_CTRL_AUXSRC_clksrc_pll_usb << CLOCKS_CLK_ADC_CTRL_AUXSRC_Pos);

  CLOCKS->CLK_RTC_DIV = (256 << CLOCKS_CLK_RTC_DIV_INT_Pos); // 12MHz / 256 = 46875 Hz
  CLOCKS->CLK_RTC_CTRL = CLOCKS_CLK_RTC_CTRL_ENABLE_Msk |
      (CLOCKS_CLK_RTC_CTRL_AUXSRC_xosc_clksrc << CLOCKS_CLK_ADC_CTRL_AUXSRC_Pos);

  // Configure 1 us tick for watchdog and timer
  WATCHDOG->TICK = ((F_REF/F_TICK) << WATCHDOG_TICK_CYCLES_Pos) | WATCHDOG_TICK_ENABLE_Msk;

  // Enable GPIOs
  RESETS_CLR->RESET = RESETS_RESET_io_bank0_Msk | RESETS_RESET_pads_bank0_Msk;
  while (0 == RESETS->RESET_DONE_b.io_bank0 || 0 == RESETS->RESET_DONE_b.pads_bank0);
}

//-----------------------------------------------------------------------------
static void serial_number_init(void)
{
  volatile uint8_t *uid = (volatile uint8_t *)0x20041f01;
  uint32_t sn = 5381;

  for (int i = 0; i < 16; i++)
    sn = ((sn << 5) + sn) ^ uid[i];

  for (int i = 0; i < 8; i++)
    usb_serial_number[i] = "0123456789ABCDEF"[(sn >> (i * 4)) & 0xf];

  usb_serial_number[8] = 0;
}

//-----------------------------------------------------------------------------
static void timer_init(void)
{
  RESETS_CLR->RESET = RESETS_RESET_timer_Msk;
  while (0 == RESETS->RESET_DONE_b.timer);

  TIMER->ALARM0 = TIMER->TIMELR + STATUS_TIMEOUT;
}

//-----------------------------------------------------------------------------
static void status_timer_task(void)
{
  if (TIMER->INTR & TIMER_INTR_ALARM_0_Msk)
  {
    TIMER->INTR = TIMER_INTR_ALARM_0_Msk;
    TIMER->ALARM0 = TIMER->TIMELR + STATUS_TIMEOUT;
    HAL_GPIO_LED_O_toggle();
  }
}

//-----------------------------------------------------------------------------
static void reset_vcp_timeout(void)
{
  TIMER->ALARM1 = TIMER->TIMELR + VCP_TIMEOUT;
}

//-----------------------------------------------------------------------------
static bool vcp_timeout(void)
{
  if (TIMER->INTR & TIMER_INTR_ALARM_1_Msk)
  {
    TIMER->INTR = TIMER_INTR_ALARM_1_Msk;
    return true;
  }
  return false;
}

//-----------------------------------------------------------------------------
static void send_buffer(void)
{
  usb_cdc_send(app_send_buffer, app_send_buffer_ptr);

  app_send_zlp = (USB_BUFFER_SIZE == app_send_buffer_ptr);
  app_send_pending = true;
  app_send_buffer_ptr = 0;
}

//-----------------------------------------------------------------------------
void usb_cdc_send_callback(void)
{
  app_send_pending = false;
}

//-----------------------------------------------------------------------------
static void display_task(void)
{
  if (!app_vcp_open)
  {
    while (SIO->FIFO_ST & SIO_FIFO_ST_VLD_Msk)
      (void)SIO->FIFO_RD;
    return;
  }

  if (app_send_pending)
    return;

  while (SIO->FIFO_ST & SIO_FIFO_ST_VLD_Msk)
  {
    app_send_buffer[app_send_buffer_ptr++] = SIO->FIFO_RD;

    reset_vcp_timeout();

    if (USB_BUFFER_SIZE == app_send_buffer_ptr)
    {
      send_buffer();
      break;
    }
  }
}

//-----------------------------------------------------------------------------
static void vcp_timer_task(void)
{
  if (vcp_timeout())
  {
    if (app_send_zlp || app_send_buffer_ptr)
      send_buffer();
  }
}

//-----------------------------------------------------------------------------
void usb_cdc_line_coding_updated(usb_cdc_line_coding_t *line_coding)
{
  (void)line_coding;
}

//-----------------------------------------------------------------------------
void usb_cdc_control_line_state_update(int line_state)
{
  app_vcp_open = (line_state & USB_CDC_CTRL_SIGNAL_DTE_PRESENT);

  if (!app_vcp_open)
    return;

  app_send_buffer_ptr = 0;

  capture_command('h');

  if (!app_recv_pending)
  {
    app_recv_pending = true;
    usb_cdc_recv(app_recv_buffer, sizeof(app_recv_buffer));
  }
}

//-----------------------------------------------------------------------------
static char lower(char c)
{
  if ('A' <= c && c <= 'Z')
    return c - ('A' - 'a');
  return c;
}

//-----------------------------------------------------------------------------
void usb_cdc_recv_callback(int size)
{
  app_recv_pending = false;

  if (!app_vcp_open)
    return;

  for (int i = 0; i < size; i++)
    capture_command(lower(app_recv_buffer[i]));

  app_recv_pending = true;
  usb_cdc_recv(app_recv_buffer, sizeof(app_recv_buffer));
}

//-----------------------------------------------------------------------------
bool usb_class_handle_request(usb_request_t *request)
{
  if (usb_cdc_handle_request(request))
    return true;
  else
    return false;
}

//-----------------------------------------------------------------------------
void usb_configuration_callback(int config)
{
  (void)config;
}

//-----------------------------------------------------------------------------
void set_error(bool error)
{
  HAL_GPIO_LED_R_write(error);
}

//-----------------------------------------------------------------------------
int main(void)
{
  sys_init();
  timer_init();
  usb_init();
  usb_cdc_init();
  serial_number_init();
  capture_init();

  HAL_GPIO_LED_O_out();
  HAL_GPIO_LED_O_clr();

  HAL_GPIO_LED_R_out();
  HAL_GPIO_LED_R_clr();

  while (1)
  {
    usb_task();
    display_task();
    vcp_timer_task();
    status_timer_task();
  }

  return 0;
}

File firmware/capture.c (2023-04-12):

// SPDX-License-Identifier: BSD-3-Clause
// Copyright (c) 2022, Alex Taradov <alex@taradov.com>. All rights reserved.

/*- Includes ----------------------------------------------------------------*/
#include <stdlib.h>
#include <stdint.h>
#include <stdbool.h>
#include <string.h>
#include "rp2040.h"
#include "hal_gpio.h"
#include "pio_asm.h"
#include "capture.h"
#include "display.h"
#include "globals.h"

/*- Definitions -------------------------------------------------------------*/
#define CORE1_STACK_SIZE       512 // words

// DP and DM can be any pins, but they must be consequitive and in that order
#define DP_INDEX       10
#define DM_INDEX       11
#define START_INDEX    12

HAL_GPIO_PIN(DP,       0, 10, pio0_10)
HAL_GPIO_PIN(DM,       0, 11, pio0_11)
HAL_GPIO_PIN(START,    0, 12, pio1_12) // Internal trigger from PIO1 to PIO0
HAL_GPIO_PIN(TRIGGER,  0, 18, sio_18)

/*- Constants ---------------------------------------------------------------*/
static const uint16_t crc16_usb_tab[256] =
{
  0x0000, 0xc0c1, 0xc181, 0x0140, 0xc301, 0x03c0, 0x0280, 0xc241,
  0xc601, 0x06c0, 0x0780, 0xc741, 0x0500, 0xc5c1, 0xc481, 0x0440,
  0xcc01, 0x0cc0, 0x0d80, 0xcd41, 0x0f00, 0xcfc1, 0xce81, 0x0e40,
  0x0a00, 0xcac1, 0xcb81, 0x0b40, 0xc901, 0x09c0, 0x0880, 0xc841,
  0xd801, 0x18c0, 0x1980, 0xd941, 0x1b00, 0xdbc1, 0xda81, 0x1a40,
  0x1e00, 0xdec1, 0xdf81, 0x1f40, 0xdd01, 0x1dc0, 0x1c80, 0xdc41,
  0x1400, 0xd4c1, 0xd581, 0x1540, 0xd701, 0x17c0, 0x1680, 0xd641,
  0xd201, 0x12c0, 0x1380, 0xd341, 0x1100, 0xd1c1, 0xd081, 0x1040,
  0xf001, 0x30c0, 0x3180, 0xf141, 0x3300, 0xf3c1, 0xf281, 0x3240,
  0x3600, 0xf6c1, 0xf781, 0x3740, 0xf501, 0x35c0, 0x3480, 0xf441,
  0x3c00, 0xfcc1, 0xfd81, 0x3d40, 0xff01, 0x3fc0, 0x3e80, 0xfe41,
  0xfa01, 0x3ac0, 0x3b80, 0xfb41, 0x3900, 0xf9c1, 0xf881, 0x3840,
  0x2800, 0xe8c1, 0xe981, 0x2940, 0xeb01, 0x2bc0, 0x2a80, 0xea41,
  0xee01, 0x2ec0, 0x2f80, 0xef41, 0x2d00, 0xedc1, 0xec81, 0x2c40,
  0xe401, 0x24c0, 0x2580, 0xe541, 0x2700, 0xe7c1, 0xe681, 0x2640,
  0x2200, 0xe2c1, 0xe381, 0x2340, 0xe101, 0x21c0, 0x2080, 0xe041,
  0xa001, 0x60c0, 0x6180, 0xa141, 0x6300, 0xa3c1, 0xa281, 0x6240,
  0x6600, 0xa6c1, 0xa781, 0x6740, 0xa501, 0x65c0, 0x6480, 0xa441,
  0x6c00, 0xacc1, 0xad81, 0x6d40, 0xaf01, 0x6fc0, 0x6e80, 0xae41,
  0xaa01, 0x6ac0, 0x6b80, 0xab41, 0x6900, 0xa9c1, 0xa881, 0x6840,
  0x7800, 0xb8c1, 0xb981, 0x7940, 0xbb01, 0x7bc0, 0x7a80, 0xba41,
  0xbe01, 0x7ec0, 0x7f80, 0xbf41, 0x7d00, 0xbdc1, 0xbc81, 0x7c40,
  0xb401, 0x74c0, 0x7580, 0xb541, 0x7700, 0xb7c1, 0xb681, 0x7640,
  0x7200, 0xb2c1, 0xb381, 0x7340, 0xb101, 0x71c0, 0x7080, 0xb041,
  0x5000, 0x90c1, 0x9181, 0x5140, 0x9301, 0x53c0, 0x5280, 0x9241,
  0x9601, 0x56c0, 0x5780, 0x9741, 0x5500, 0x95c1, 0x9481, 0x5440,
  0x9c01, 0x5cc0, 0x5d80, 0x9d41, 0x5f00, 0x9fc1, 0x9e81, 0x5e40,
  0x5a00, 0x9ac1, 0x9b81, 0x5b40, 0x9901, 0x59c0, 0x5880, 0x9841,
  0x8801, 0x48c0, 0x4980, 0x8941, 0x4b00, 0x8bc1, 0x8a81, 0x4a40,
  0x4e00, 0x8ec1, 0x8f81, 0x4f40, 0x8d01, 0x4dc0, 0x4c80, 0x8c41,
  0x4400, 0x84c1, 0x8581, 0x4540, 0x8701, 0x47c0, 0x4680, 0x8641,
  0x8201, 0x42c0, 0x4380, 0x8341, 0x4100, 0x81c1, 0x8081, 0x4040,
};

static const uint8_t crc5_usb_tab[256] =
{
  0x00, 0x0e, 0x1c, 0x12, 0x11, 0x1f, 0x0d, 0x03, 0x0b, 0x05, 0x17, 0x19, 0x1a, 0x14, 0x06, 0x08,
  0x16, 0x18, 0x0a, 0x04, 0x07, 0x09, 0x1b, 0x15, 0x1d, 0x13, 0x01, 0x0f, 0x0c, 0x02, 0x10, 0x1e,
  0x05, 0x0b, 0x19, 0x17, 0x14, 0x1a, 0x08, 0x06, 0x0e, 0x00, 0x12, 0x1c, 0x1f, 0x11, 0x03, 0x0d,
  0x13, 0x1d, 0x0f, 0x01, 0x02, 0x0c, 0x1e, 0x10, 0x18, 0x16, 0x04, 0x0a, 0x09, 0x07, 0x15, 0x1b,
  0x0a, 0x04, 0x16, 0x18, 0x1b, 0x15, 0x07, 0x09, 0x01, 0x0f, 0x1d, 0x13, 0x10, 0x1e, 0x0c, 0x02,
  0x1c, 0x12, 0x00, 0x0e, 0x0d, 0x03, 0x11, 0x1f, 0x17, 0x19, 0x0b, 0x05, 0x06, 0x08, 0x1a, 0x14,
  0x0f, 0x01, 0x13, 0x1d, 0x1e, 0x10, 0x02, 0x0c, 0x04, 0x0a, 0x18, 0x16, 0x15, 0x1b, 0x09, 0x07,
  0x19, 0x17, 0x05, 0x0b, 0x08, 0x06, 0x14, 0x1a, 0x12, 0x1c, 0x0e, 0x00, 0x03, 0x0d, 0x1f, 0x11,
  0x14, 0x1a, 0x08, 0x06, 0x05, 0x0b, 0x19, 0x17, 0x1f, 0x11, 0x03, 0x0d, 0x0e, 0x00, 0x12, 0x1c,
  0x02, 0x0c, 0x1e, 0x10, 0x13, 0x1d, 0x0f, 0x01, 0x09, 0x07, 0x15, 0x1b, 0x18, 0x16, 0x04, 0x0a,
  0x11, 0x1f, 0x0d, 0x03, 0x00, 0x0e, 0x1c, 0x12, 0x1a, 0x14, 0x06, 0x08, 0x0b, 0x05, 0x17, 0x19,
  0x07, 0x09, 0x1b, 0x15, 0x16, 0x18, 0x0a, 0x04, 0x0c, 0x02, 0x10, 0x1e, 0x1d, 0x13, 0x01, 0x0f,
  0x1e, 0x10, 0x02, 0x0c, 0x0f, 0x01, 0x13, 0x1d, 0x15, 0x1b, 0x09, 0x07, 0x04, 0x0a, 0x18, 0x16,
  0x08, 0x06, 0x14, 0x1a, 0x19, 0x17, 0x05, 0x0b, 0x03, 0x0d, 0x1f, 0x11, 0x12, 0x1c, 0x0e, 0x00,
  0x1b, 0x15, 0x07, 0x09, 0x0a, 0x04, 0x16, 0x18, 0x10, 0x1e, 0x0c, 0x02, 0x01, 0x0f, 0x1d, 0x13,
  0x0d, 0x03, 0x11, 0x1f, 0x1c, 0x12, 0x00, 0x0e, 0x06, 0x08, 0x1a, 0x14, 0x17, 0x19, 0x0b, 0x05,
};

static const char *capture_speed_str[CaptureSpeedCount] =
{
  [CaptureSpeed_Low]  = "Low",
  [CaptureSpeed_Full] = "Full",
};

static const char *capture_trigger_str[CaptureTriggerCount] =
{
  [CaptureTrigger_Enabled]  = "Enabled",
  [CaptureTrigger_Disabled] = "Disabled",
};

static const char *capture_limit_str[CaptureLimitCount] =
{
  [CaptureLimit_100]       = "100 packets",
  [CaptureLimit_200]       = "200 packets",
  [CaptureLimit_500]       = "500 packets",
  [CaptureLimit_1000]      = "1000 packets",
  [CaptureLimit_2000]      = "2000 packets",
  [CaptureLimit_5000]      = "5000 packets",
  [CaptureLimit_10000]     = "10000 packets",
  [CaptureLimit_Unlimited] = "Unlimited",
};

static const char *display_time_str[DisplayTimeCount] =
{
  [DisplayTime_First]    = "Relative to the first packet",
  [DisplayTime_Previous] = "Relative to the previous packet",
  [DisplayTime_SOF]      = "Relative to the SOF",
  [DisplayTime_Reset]    = "Relative to the bus reset",
};

static const char *display_data_str[DisplayDataCount] =
{
  [DisplayData_Full]    = "Full",
  [DisplayData_Limit16] = "Limit to 16 bytes",
  [DisplayData_Limit64] = "Limit to 64 bytes",
  [DisplayData_None]    = "Do not display data",
};

static const char *display_fold_str[DisplayFoldCount] =
{
  [DisplayFold_Enabled]  = "Enabled",
  [DisplayFold_Disabled] = "Disabled",
};

/*- Variables ---------------------------------------------------------------*/
uint32_t g_buffer[BUFFER_SIZE];
buffer_info_t g_buffer_info;

int g_capture_speed   = CaptureSpeed_Full;
int g_capture_trigger = CaptureTrigger_Disabled;
int g_capture_limit   = CaptureLimit_Unlimited;
int g_display_time    = DisplayTime_SOF;
int g_display_data    = DisplayData_Full;
int g_display_fold    = DisplayFold_Enabled;

static int g_rd_ptr    = 0;
static int g_wr_ptr    = 0;
static int g_sof_index = 0;
static bool g_may_fold = false;

/*- Implementations ---------------------------------------------------------*/

//-----------------------------------------------------------------------------
static uint16_t crc16_usb(uint8_t *data, int size)
{
  uint16_t crc = 0xffff;

  for (int i = 0; i < size; i++)
    crc = crc16_usb_tab[(crc ^ data[i]) & 0xff] ^ (crc >> 8);

  return crc;
}
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

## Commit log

2022-02-20 Added custom board pictures
2022-02-20 Moved custom board stuff into a different doc
2023-04-12 Added hardware design files
    [usb-sniffer-lite.kicad_pcb, usb-sniffer-lite.kicad_sch]
2023-04-15 Added case model and STL files
    [Case-Device.FCStd, Case-Device.stl, Case-Target.FCStd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]
